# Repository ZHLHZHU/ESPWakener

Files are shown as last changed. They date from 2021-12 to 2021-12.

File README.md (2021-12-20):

## 简介
EspWakener是一个基于Wake-on-LAN协议的网络唤醒器，通过MQTT协议进行控制。

## 配置说明
* 把开关拨到"ON"，通电（顺序不能乱）。连上Wakener发出的热点，进入192.168.8.1（你都看到本页面了，肯定已经完成这些步骤）。
* 进入Config页签，配置好WIFI名和密码、WOL的端口（默认9）。
* 打开MQTT开关，填入MQTT连接（只支持mqtt://协议，不支持TLS和WS），填入Topic。MQTT用户名和密码如果没有可以忽略。
* 点击保存，把开关拨到"1"，断电，通电。（拨开关和断电的顺序任意，因为本设备只会根据通电瞬间的开关状态来判断是否进入配置模式）。
## 协议
### Wakener上线
当Wakener成功连接Mqtt服务器后，会广播一条自身状态的信息
```json
{
    "action": "join",
    "sender": "SwingFrogWakener",
    "deviceName": "SwingFrogWakener",
    "ip": "192.168.1.188",
    "ssid": "WIFI_NAME",
    "rssi": -47,
    "version": "2.0.0"
}
```
### 请求唤醒
向Wakener所配置的Topic发送以下指令，Wakener将会在所在局域网广播唤醒包
MAC地址分隔符支持 ':' 和 '-'
```json
{
    "action": "wake",
    "mac": "a9:a9:59:30:d8:ee"
}
```
### 请求设备状态
向Wakener所配置的Topic发送以下指令，将会返回Wakener当前状态信息
```json
{
    "action": "info"
}
```

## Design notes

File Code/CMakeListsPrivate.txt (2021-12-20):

# !!! WARNING !!! AUTO-GENERATED FILE, PLEASE DO NOT MODIFY IT AND USE
# https://docs.platformio.org/page/projectconf/section_env_build.html#build-flags
#
# If you need to override existing CMake configuration or add extra,
# please create `CMakeListsUser.txt` in the root of project.
# The `CMakeListsUser.txt` will not be overwritten by PlatformIO.

set(CMAKE_CONFIGURATION_TYPES "esp12e" CACHE STRING "Build Types reflect PlatformIO Environments" FORCE)

SET(CMAKE_C_COMPILER "$ENV{HOME}/.platformio/packages/toolchain-xtensa/bin/xtensa-lx106-elf-gcc")
SET(CMAKE_CXX_COMPILER "$ENV{HOME}/.platformio/packages/toolchain-xtensa/bin/xtensa-lx106-elf-g++")
SET(CMAKE_CXX_FLAGS "-fno-rtti -std=gnu++17 -fno-exceptions -Os -mlongcalls -mtext-section-literals -falign-functions=4 -U__STRICT_ANSI__ -D_GNU_SOURCE -ffunction-sections -fdata-sections -Wall -Werror=return-type -free -fipa-pta")
SET(CMAKE_C_FLAGS "-std=gnu17 -Wpointer-arith -Wno-implicit-function-declaration -Wl,-EL -fno-inline-functions -nostdlib -Os -mlongcalls -mtext-section-literals -falign-functions=4 -U__STRICT_ANSI__ -D_GNU_SOURCE -ffunction-sections -fdata-sections -Wall -Werror=return-type -free -fipa-pta")

SET(CMAKE_C_STANDARD 17)
set(CMAKE_CXX_STANDARD 17)

if (CMAKE_BUILD_TYPE MATCHES "esp12e")
    add_definitions(-DPLATFORMIO=50203)
    add_definitions(-DESP8266)
    add_definitions(-DARDUINO_ARCH_ESP8266)
    add_definitions(-DARDUINO_ESP8266_ESP12)
    add_definitions(-DF_CPU=80000000L)
    add_definitions(-D__ets__)
    add_definitions(-DICACHE_FLASH)
    add_definitions(-DARDUINO=10805)
    add_definitions(-DARDUINO_BOARD=\"PLATFORMIO_ESP12E\")
    add_definitions(-DFLASHMODE_DIO)
    add_definitions(-DLWIP_OPEN_SRC)
    add_definitions(-DNONOSDK22x_190703=1)
    add_definitions(-DTCP_MSS=536)
    add_definitions(-DLWIP_FEATURES=1)
    add_definitions(-DLWIP_IPV6=0)
    add_definitions(-DVTABLES_IN_FLASH)
    add_definitions(-DMMU_IRAM_SIZE=0x8000)
    add_definitions(-DMMU_ICACHE_SIZE=0x8000)

    include_directories("${CMAKE_CURRENT_LIST_DIR}/include")
    include_directories("${CMAKE_CURRENT_LIST_DIR}/src")
    include_directories("$ENV{HOME}/.platformio/packages/framework-arduinoespressif8266/libraries/ArduinoOTA")
    include_directories("$ENV{HOME}/.platformio/packages/framework-arduinoespressif8266/libraries/ESP8266mDNS/src")
    include_directories("$ENV{HOME}/.platformio/packages/framework-arduinoespressif8266/libraries/LittleFS/src")
    include_directories("${CMAKE_CURRENT_LIST_DIR}/.pio/libdeps/esp12e/Regexp/src")
    include_directories("${CMAKE_CURRENT_LIST_DIR}/.pio/libdeps/esp12e/PubSubClient/src")
    include_directories("${CMAKE_CURRENT_LIST_DIR}/.pio/libdeps/esp12e/ESP Async WebServer/src")
    include_directories("$ENV{HOME}/.platformio/packages/framework-arduinoespressif8266/libraries/ESP8266WiFi/src")
    include_directories("${CMAKE_CURRENT_LIST_DIR}/.pio/libdeps/esp12e/ArduinoJson/src")
    include_directories("$ENV{HOME}/.platformio/packages/framework-arduinoespressif8266/libraries/Hash/src")
    include_directories("${CMAKE_CURRENT_LIST_DIR}/.pio/libdeps/esp12e/ESPAsyncTCP/src")
    include_directories("$ENV{HOME}/.platformio/packages/framework-arduinoespressif8266/tools/sdk/include")
    include_directories("$ENV{HOME}/.platformio/packages/framework-arduinoespressif8266/cores/esp8266")
    include_directories("$ENV{HOME}/.platformio/packages/toolchain-xtensa/include")
    include_directories("$ENV{HOME}/.platformio/packages/framework-arduinoespressif8266/tools/sdk/lwip2/include")
    include_directories("$ENV{HOME}/.platformio/packages/framework-arduinoespressif8266/variants/nodemcu")
    include_directories("$ENV{HOME}/.platformio/packages/framework-arduinoespressif8266/libraries/DNSServer/src")
    include_directories("$ENV{HOME}/.platformio/packages/framework-arduinoespressif8266/libraries/EEPROM")
    include_directories("$ENV{HOME}/.platformio/packages/framework-arduinoespressif8266/libraries/ESP8266AVRISP/src")
    include_directories("$ENV{HOME}/.platformio/packages/framework-arduinoespressif8266/libraries/ESP8266HTTPClient/src")
    include_directories("$ENV{HOME}/.platformio/packages/framework-arduinoespressif8266/libraries/ESP8266HTTPUpdateServer/src")
    include_directories("$ENV{HOME}/.platformio/packages/framework-arduinoespressif8266/libraries/ESP8266LLMNR")
    include_directories("$ENV{HOME}/.platformio/packages/framework-arduinoespressif8266/libraries/ESP8266NetBIOS")
    include_directories("$ENV{HOME}/.platformio/packages/framework-arduinoespressif8266/libraries/ESP8266SSDP")
    include_directories("$ENV{HOME}/.platformio/packages/framework-arduinoespressif8266/libraries/ESP8266SdFat/src")
    include_directories("$ENV{HOME}/.platformio/packages/framework-arduinoespressif8266/libraries/ESP8266WebServer/src")
    include_directories("$ENV{HOME}/.platformio/packages/framework-arduinoespressif8266/libraries/ESP8266WiFiMesh/src")
    include_directories("$ENV{HOME}/.platformio/packages/framework-arduinoespressif8266/libraries/ESP8266httpUpdate/src")
    include_directories("$ENV{HOME}/.platformio/packages/framework-arduinoespressif8266/libraries/Ethernet/src")
    include_directories("$ENV{HOME}/.platformio/packages/framework-arduinoespressif8266/libraries/GDBStub/src")
    include_directories("$ENV{HOME}/.platformio/packages/framework-arduinoespressif8266/libraries/I2S/src")
    include_directories("$ENV{HOME}/.platformio/packages/framework-arduinoespressif8266/libraries/Netdump/src")
    include_directories("$ENV{HOME}/.platformio/packages/framework-arduinoespressif8266/libraries/SD/src")
    include_directories("$ENV{HOME}/.platformio/packages/framework-arduinoespressif8266/libraries/SDFS/src")
    include_directories("$ENV{HOME}/.platformio/packages/framework-arduinoespressif8266/libraries/SPI")
    include_directories("$ENV{HOME}/.platformio/packages/framework-arduinoespressif8266/libraries/SPISlave/src")
    include_directories("$ENV{HOME}/.platformio/packages/framework-arduinoespressif8266/libraries/Servo/src")
    include_directories("$ENV{HOME}/.platformio/packages/framework-arduinoespressif8266/libraries/SoftwareSerial/src")
    include_directories("$ENV{HOME}/.platformio/packages/framework-arduinoespressif8266/libraries/TFT_Touch_Shield_V2")
    include_directories("$ENV{HOME}/.platformio/packages/framework-arduinoespressif8266/libraries/Ticker/src")
    include_directories("$ENV{HOME}/.platformio/packages/framework-arduinoespressif8266/libraries/Wire")
    include_directories("$ENV{HOME}/.platformio/packages/framework-arduinoespressif8266/libraries/esp8266/src")
    include_directories("$ENV{HOME}/.platformio/packages/framework-arduinoespressif8266/libraries/lwIP_PPP/src")
    include_directories("$ENV{HOME}/.platformio/packages/framework-arduinoespressif8266/libraries/lwIP_enc28j60/src")
    include_directories("$ENV{HOME}/.platformio/packages/framework-arduinoespressif8266/libraries/lwIP_w5100/src")
    include_directories("$ENV{HOME}/.platformio/packages/framework-arduinoespressif8266/libraries/lwIP_w5500/src")
    include_directories("$ENV{HOME}/.platformio/packages/toolchain-xtensa/xtensa-lx106-elf/include/c++/10.3.0")
    include_directories("$ENV{HOME}/.platformio/packages/toolchain-xtensa/xtensa-lx106-elf/include/c++/10.3.0/xtensa-lx106-elf")
    include_directories("$ENV{HOME}/.platformio/packages/toolchain-xtensa/lib/gcc/xtensa-lx106-elf/10.3.0/include")
    include_directories("$ENV{HOME}/.platformio/packages/toolchain-xtensa/lib/gcc/xtensa-lx106-elf/10.3.0/include-fixed")
    include_directories("$ENV{HOME}/.platformio/packages/toolchain-xtensa/xtensa-lx106-elf/include")
    include_directories("$ENV{HOME}/.platformio/packages/tool-unity")

    FILE(GLOB_RECURSE EXTRA_LIB_SOURCES
        ${CMAKE_CURRENT_LIST_DIR}/.pio/libdeps/esp12e/*.*
    )
endif()

FILE(GLOB_RECURSE SRC_LIST
    ${CMAKE_CURRENT_LIST_DIR}/src/*.*
    ${CMAKE_CURRENT_LIST_DIR}/lib/*.*
    ${CMAKE_CURRENT_LIST_DIR}/test/*.*
)

list(APPEND SRC_LIST ${EXTRA_LIB_SOURCES})

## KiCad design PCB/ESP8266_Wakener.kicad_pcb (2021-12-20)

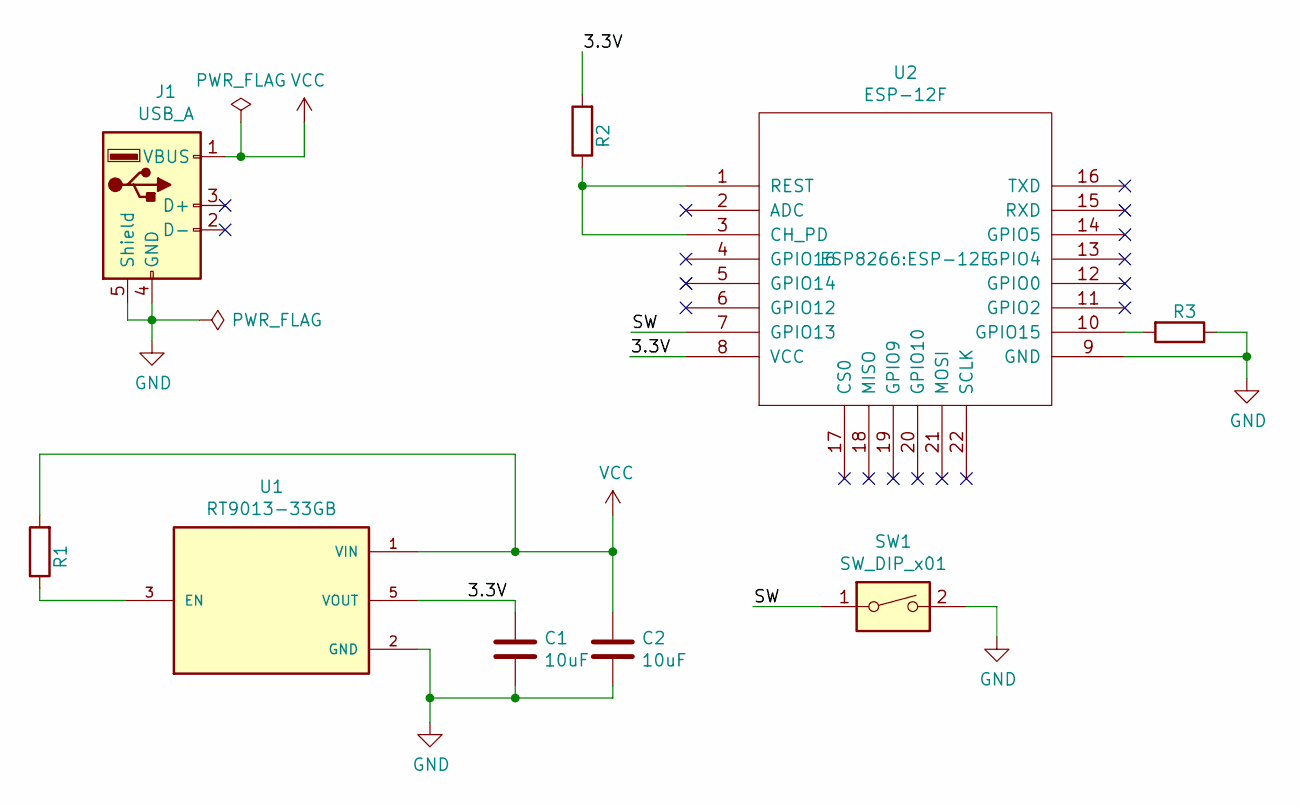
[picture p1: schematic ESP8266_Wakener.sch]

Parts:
C1, C2: 10uF; C_0603_1608Metric
J1: USB_A; USB_A_CNCTech_1001-011-01101_Horizontal
R1, R2, R3: 10K; R_0603_1608Metric
SW1: SW_DIP_x01; SW_SMT_1P
U1: RT9013-33GB; SOT-23-5_HandSoldering; PARTREV Aprill 2011
U2: ESP-12F; ESP-12E

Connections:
/3.3V: C1.1, R2.2, U1.5 (VOUT), U2.8 (VCC)
/SW: SW1.1, U2.7 (GPIO13)
GND: C1.2, C2.2, J1.4 (GND), J1.5 (Shield), R3.1, SW1.2, U1.2 (GND), U2.9 (GND)
unnamed: R1.1, U1.3 (EN)
unnamed: R2.1, U2.1 (REST), U2.3 (CH_PD)
unnamed: R3.2, U2.10 (GPIO15)
VCC: C2.1, J1.1 (VBUS), R1.2, U1.1 (VIN)

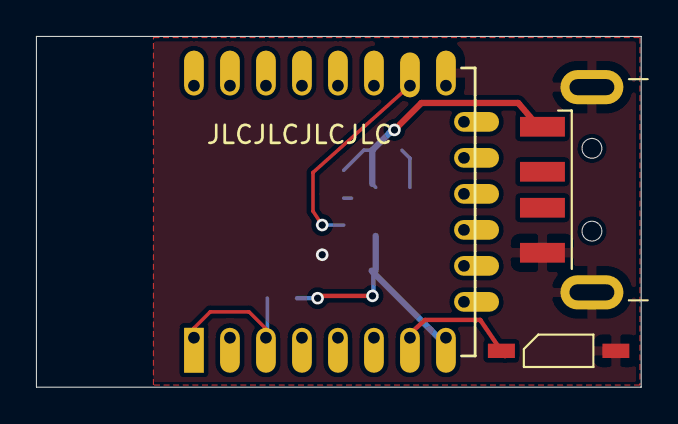
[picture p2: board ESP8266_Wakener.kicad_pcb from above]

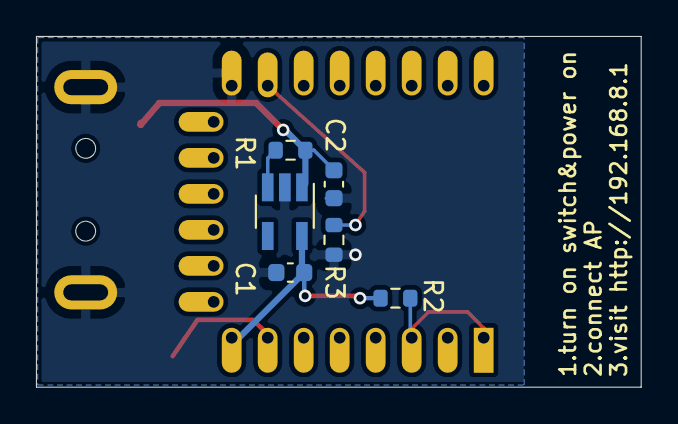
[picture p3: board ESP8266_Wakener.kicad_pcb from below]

Board: 2 copper layers, 33.6 x 19.5 mm, 9 parts (6 on the bottom side), 7 nets.

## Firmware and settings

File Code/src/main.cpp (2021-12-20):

#include <Arduino.h>
#include <ESP8266WiFi.h>
#include <ESPAsyncTCP.h>
#include <mqtt.h>
#include <config.h>
#include <web.h>

void initAP()
{
  IPAddress localIP(192, 168, 8, 1);
  WiFi.softAPConfig(localIP, localIP, IPAddress(255, 255, 255, 0));
  WiFi.softAP(DEVICE_NAME, "");
}

void connectWiFi()
{
  WiFi.begin(config.stSSID, config.stPASS);
  ESP8266WiFiClass::persistent(false);
  Serial.print("Connecting");
  while (WiFi.status() != WL_CONNECTED)
  {
    delay(2000);
    Serial.print(".");
  }
  Serial.println("Connected, IP address: ");
  Serial.println(WiFi.localIP());
}

void initOTA()
{
  ArduinoOTA.onStart(
      []()
      {
        String type;
        Serial.println(ArduinoOTA.getCommand());
        if (ArduinoOTA.getCommand() == U_FLASH)
          type = "sketch";
        else // U_SPIFFS
          type = "filesystem";

        // NOTE: if updating SPIFFS this would be the place to unmount SPIFFS using SPIFFS.end()
        Serial.println("Start updating " + type);
      });

  ArduinoOTA.onEnd(
      []()
      { Serial.println("\nEnd"); });

  ArduinoOTA.onProgress(
      [](unsigned int progress, unsigned int total)
      { Serial.printf("Progress: %u%%\r", (progress / (total / 100))); });

  ArduinoOTA.onError(
      [](ota_error_t error)
      {
        Serial.printf("Error[%u]: ", error);
        if (error == OTA_AUTH_ERROR)
          Serial.println("Auth Failed");
        else if (error == OTA_BEGIN_ERROR)
          Serial.println("Begin Failed");
        else if (error == OTA_CONNECT_ERROR)
          Serial.println("Connect Failed");
        else if (error == OTA_RECEIVE_ERROR)
          Serial.println("Receive Failed");
        else if (error == OTA_END_ERROR)
          Serial.println("End Failed");
      });
  ArduinoOTA.begin();
}

void setup()
{
  Serial.begin(115200);
  LittleFS.begin();
  loadConfig();
  // init gpio
  pinMode(CONFIG_SWITCH_PIN, INPUT_PULLUP);
  configMode = digitalRead(CONFIG_SWITCH_PIN) == LOW;
#ifdef DEBUG
  initOTA();
#endif
  if (configMode)
  {
    Serial.println("config mode");
    initAP();
    initWebServer();
    pinMode(CONFIG_LED_PIN, OUTPUT);
    initOTA();
  }
  else
  {
    connectWiFi();
    if (!config.mqttHost.isEmpty())
    {
      initMqtt();
    }
  }
}

void loop()
{
  if (WiFi.status() == WL_CONNECTED && !config.mqttHost.isEmpty() && !mqtt.connected())
  {
    mqttReconnect();
  }
  mqtt.loop();
#ifdef DEBUG
  ArduinoOTA.handle();
#endif
  if (configMode)
  {
    ArduinoOTA.handle();
    digitalWrite(CONFIG_LED_PIN, !digitalRead(CONFIG_LED_PIN));
  }
  delay(1000);
}

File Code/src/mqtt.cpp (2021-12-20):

#include <mqtt.h>

WiFiClient wifiClient;
PubSubClient mqtt(wifiClient);

void mqttCallback(char *topic, byte *payload, unsigned int length)
{
  if (config.mqttTopic != topic)
  {
    Serial.println("receive out of topic message");
    return;
  }
  StaticJsonDocument<256> doc;
  DeserializationError error = deserializeJson(doc, payload, length);
  if (error)
  {
    Serial.println("Failed to parse JSON");
    return;
  }
  String action = doc["action"] | "";
  String sender = doc["sender"] | "";
  if (sender == DEVICE_NAME)
  {
    return;
  }
  StaticJsonDocument<256> res;
  res["sender"] = DEVICE_NAME;
  char buffer[256];
  if (action == "wake")
  {
    String mac = doc["mac"] | "";
    if (mac.isEmpty())
    {
      res["code"] = 400;
      res["message"] = "mac address is empty.";
      serializeJson(res, buffer);
      mqtt.publish(config.mqttTopic.c_str(), buffer, true);
      return;
    }
    if(!isMacAddress(mac)){
        res["code"] = 400;
        res["message"] = "mac address invalid.";
        serializeJson(res, buffer);
        mqtt.publish(config.mqttTopic.c_str(), buffer, true);
        return;
    }
    String wakeRes = wakeByMacStr(mac);
    // wake failed
    if(!wakeRes.isEmpty())
    {
      res["code"] = 400;
      res["message"] = wakeRes;
      serializeJson(res, buffer);
      mqtt.publish(config.mqttTopic.c_str(), buffer, true);
      return;
    }
    //success to wake
    res["code"] = 200;
    res["message"] = "success,already send magic package to " + mac;
    serializeJson(res, buffer);
    mqtt.publish(config.mqttTopic.c_str(), buffer, true);
    return;
  }
  if (action == "info")
  {
    resDeviceInfo("resInfo");
    return;
  }
}

void mqttReconnect()
{
  // Loop until we're reconnected
  while (!mqtt.connected())
  {
    Serial.print("Attempting MQTT connection...");
    // Attempt to connect
    if (mqttConnect())
    {
      Serial.println("connected");
      //resubscribe
      mqtt.subscribe(config.mqttTopic.c_str(), 0);
      resDeviceInfo("join");
    }
    else
    {
      Serial.print("failed, rc=");
      Serial.print(mqtt.state());
      Serial.println(" try again in 5 seconds");
      // Wait 10 seconds before retrying
        delay(10000);
    }

  }
}

bool mqttConnect()
{
  String username = config.mqttUsername;
  String password = config.mqttPass;
  return mqtt.connect((String(DEVICE_NAME)+"_"+ random(2021)).c_str(),
                      username.isEmpty() ? nullptr : username.c_str(),
                      password.isEmpty() ? nullptr : password.c_str());
}

void initMqtt()
{
  mqtt.setServer(config.mqttHost.c_str(), config.mqttPort);
  mqtt.setCallback(mqttCallback);
}

void resDeviceInfo(const char *action){
    StaticJsonDocument<256> res;
    res["action"] = action;
    res["sender"] = DEVICE_NAME;
    res["deviceName"] = DEVICE_NAME;
    res["ip"] = WiFi.localIP().toString();
    res["ssid"] = WiFi.SSID();
    res["rssi"] = WiFi.RSSI();
    res["version"] = FIRMWARE_VERSION;
    char buffer[256];
    serializeJson(res, buffer);
    mqtt.publish(config.mqttTopic.c_str(), buffer, true);
}
